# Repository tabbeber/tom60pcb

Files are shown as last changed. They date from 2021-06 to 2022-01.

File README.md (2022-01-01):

# Configuring PCB
To configure this PCB, head over to my [config repository](https://github.com/tabbeber/zmk-config). Follow the instructions there, and you should be set at modifying the keymap.

# About

This project is inspired by [isometria75](https://github.com/ebastler/isometria-75). 
Schematics and parts were used as a baseline, together with some information from the [nrfMicro-project](https://github.com/joric/nrfmicro/). 
Also thanks to Martin in the Norwegian mechanical keyboard discord for feedback and a slick logo to put on it.

What this project attempts to do is to fill a gap in the mid-tier of the custom mechanical keyboard market, where bluetooth/wireless boards are few and far between. 
Most of them are closed source or difficult to get hold of.
This is also mostly a project for me build skills within PCB design.
Feel free to come with any feedback - I have no clue what I'm doing.

This project was originally born out of an idea to create a PCB which was specifically made for gummyworm-mounting in regular tray mount cases without needing to massacre the poor case.
Eventually the PCB looked decent, and regular tray mount PCB would likely have a broader appeal than some hacky gummywork gasket.

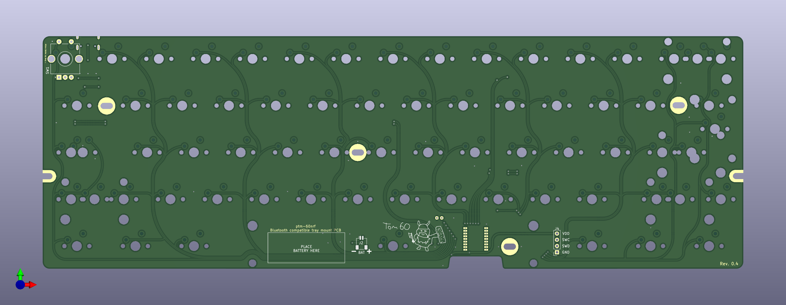
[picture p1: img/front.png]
PCB Front


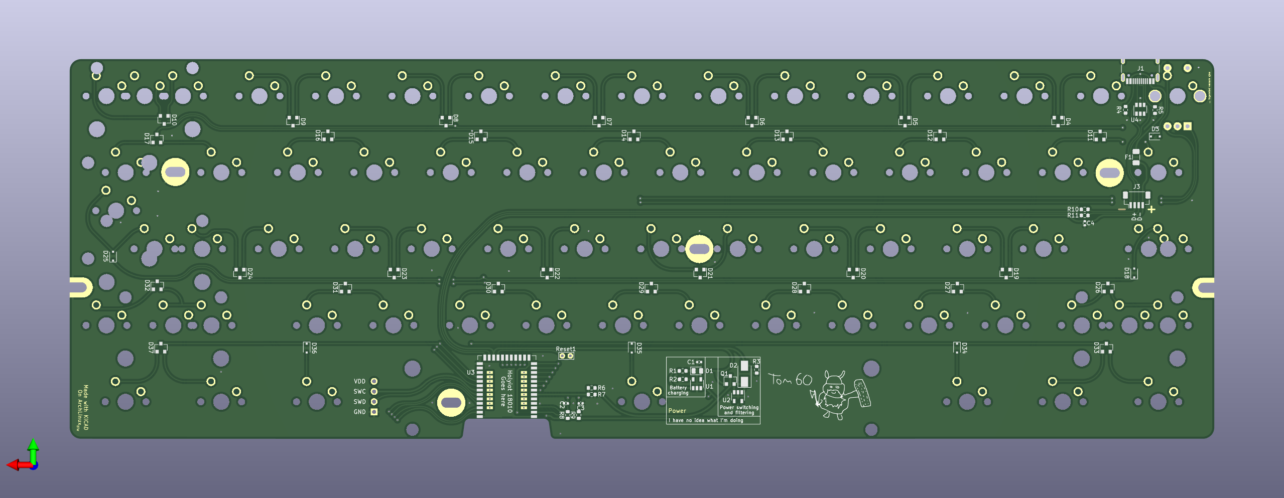
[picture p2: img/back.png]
PCB Back


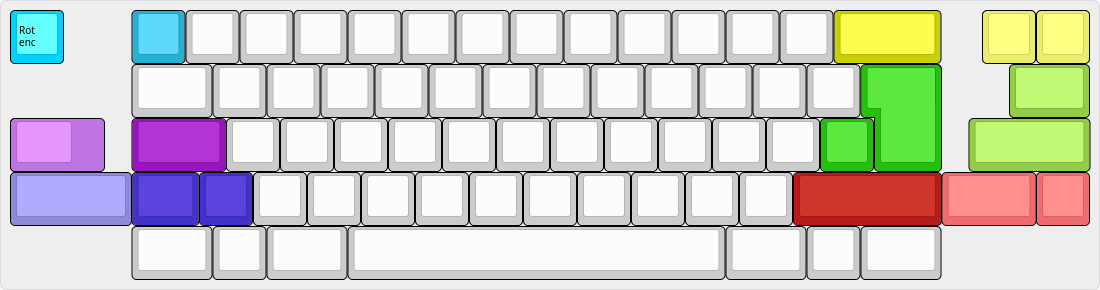
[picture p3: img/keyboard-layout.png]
Supported layouts


# Current parts

Currently this design requires a [smaller lithium battery](https://www.aliexpress.com/item/32831998939.html), which is placed between the PCB and plate of the build.
These batteries are only 3mm tall, 30mm long and 12mm wide.
This approach is not suited for plateless builds.
Ideally uses a 2-pin JST connector, but can probably also be soldered directly to the PCB.

This PCB uses the same [Holyiot 18010](https://www.aliexpress.com/item/32868002366.html) chip that the isometria75 does. This chip comes without a bootloader, and thus need to be programmed before use.

Currently the PCB uses a forced tsangan layout for the bottom row to make space for the MCU and the battery, while the rest should be fairly universal; support for split backspace, iso and ansi.

# Current progress

Currently the project requires some more work with its footprints, but it's almost ready for prototyping. No parts are currently ordered for the future prototype.

# To-do
- [x] Make a supported layout chart
- [x] Order Battery, MCU, and Programmer for the MCU
- [x] Fix PCB and final touchups
- [x] Order PCB prototype
	* PCB rev. 0.2 has arrived
	* Current revision mostly contain cosmetic changes and improved via placements - the electrical and functional configuration remain very similar to rev. 0.2
- [x] Write and configure firmware (bootloader, ZMK)
	* ZMK firmware is functional. Currently need to figure out uploading and creating a github actions repo, as per ZMK guidelines.
- [ ] Possibly make a small wiki?

# Future possibilities

* Use of different chip(format), like the nRF52840 in the E73 format, which seem abundant on aliexpress
* Modified versions for ortho, gummyworm mount, and through-hole kits.

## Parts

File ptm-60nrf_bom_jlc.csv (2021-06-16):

Comment | Designator | Footprint | LCSC Part #
1nF | C1 | C_0402_1005Metric | C1523
100nF | C2,C3 | C_0402_1005Metric | C1525
10nF | C4 | R_0402_1005Metric | C15195
RED | D1 | LED_0805_2012Metric | C84256
SS14 | D2 | D_SMA | C2480
BAV70 | D4,D5,D6,D7,D8,D9,D10,D11,D12,D13,D14,D15,D16,D17,D19,D20,D21,D22,D23,D24,D26,D27,D28,D29,D30,D31,D32,D37,D33 | SOT-23 | C68978
1n4148 | D18,D25,D34,D35,D36,D3 | D_SOD-323F | C2128
500mA | F1 | Fuse_1206_3216Metric | C70069
USB_C_Receptacle_USB2.0 | J1 | USB_C_Receptacle_HRO_TYPE-C-31-M-12 | C165948
AO3407 | Q1 | SOT-23 | C181093
1K | R1 | R_0603_1608Metric | C21190
10K | R2 | R_0603_1608Metric | C25804
100k | R3 | R_0603_1608Metric | C25803
5.1K | R4,R5 | R_0603_1608Metric | C23186
1M | R6 | R_0603_1608Metric | C22935
2M | R7 | R_0603_1608Metric | C22766
10k | R9,R8 | R_0603_1608Metric | C25804
TP4054 | U1 | SOT-23-5 | C32574
XC6220B331MR-G | U2 | SOT-23-5 | C86534
SRV05-4 | U4 | SOT-23-6 | C85364

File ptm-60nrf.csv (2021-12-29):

Id | Designator | Package | Quantity | Designation | Supplier and ref
1 | HOLE | PKRH | 1 | VAL**
2 | MX66 | MXOnly-7U-ReversedStabilizers-NoLED | 1 | MX-NoLED
3 | HOLE,HOLE,HOLE | PKRH | 3 | VAL**
4 | J2 | JST_SH_SM02B-SRSS-TB_1x02-1MP_P1.00mm_Horizontal | 1 | BAT
5 | J4 | PinSocket_1x04_P2.54mm_Vertical | 1 | SWD
6 | MX2,MX3,MX4,MX5,MX7,MX8,MX9,MX10,MX11,MX12,MX13,MX14,MX18,MX20,MX21,MX22,MX23,MX24,MX25,MX26,MX27,MX28,MX29,MX33,MX34,MX35,MX36,MX37,MX38,MX39,MX40,MX41,MX42,MX43,MX49,MX50,MX51,MX52,MX53,MX54,MX57,MX59,MX62,MX64,MX68,MX6,MX16,MX1,MX19,MX44,MX58,MX56,MX55 | MXOnly-1U-NoLED | 53 | MX-NoLED
7 | MX15 | MXOnly-2U-NoLED | 1 | MX-NoLED
8 | MX17,MX30,MX65,MX67,MX69,MX63 | MXOnly-1.5U-NoLED | 6 | MX-NoLED
9 | MX31,MX47 | MXOnly-1.25U-NoLED | 2 | MX-NoLED
10 | MX45,MX48 | MXOnly-2.25U-NoLED | 2 | MX-NoLED
11 | MX60,MX32 | MXOnly-1.75U-NoLED | 2 | MX-NoLED
12 | MX61 | MXOnly-2.75U-NoLED | 1 | MX-NoLED
13 | MX46 | MXOnly-ISO-ReversedStabilizers | 1 | MX-NoLED
14 | HOLE,HOLE | PKRHSL | 2 | VAL**
15 | SW1 | RotaryEncoder_Alps_EC11E-Switch_Vertical_H20mm | 1 | Rotary_Encoder_Switch
16 | G***,G*** | tomlogoliten | 2 | LOGO
17 | D1 | LED_0805_2012Metric | 1 | RED
18 | D18,D34,D3,D25,D35,D36 | D_SOD-323F | 6 | 1n4148
19 | Q1 | SOT-23 | 1 | AO3407
20 | R1 | R_0603_1608Metric | 1 | 1K
21 | R2 | R_0603_1608Metric | 1 | 10K
22 | R3 | R_0603_1608Metric | 1 | 100k
23 | R6 | R_0603_1608Metric | 1 | 1M
24 | U2 | SOT-23-5 | 1 | XC6220B331MR-G
25 | R7 | R_0603_1608Metric | 1 | 2M
26 | J1 | USB_C_Receptacle_HRO_TYPE-C-31-M-12 | 1 | USB_C_Receptacle_USB2.0
27 | D2 | D_SMA | 1 | SS14
28 | U3 | nRF52840_holyiot_18010 | 1 | nRF52840_holyiot_18010
29 | U4 | SOT-23-6 | 1 | SRV05-4
30 | R4,R5 | R_0603_1608Metric | 2 | 5.1K
31 | U1 | SOT-23-5 | 1 | TP4054
32 | D4,D5,D6,D7,D8,D9,D10,D13,D14,D15,D16,D17,D19,D20,D21,D22,D23,D24,D26,D27,D28,D29,D30,D32,D37,D11,D12,D31,D33 | SOT-23 | 29 | BAV70
33 | C1 | C_0402_1005Metric | 1 | 1nF
34 | J3 | JST_SH_BM04B-SRSS-TB_1x04-1MP_P1.00mm_Vertical | 1 | Conn_01x04_Male
35 | F1 | Fuse_1206_3216Metric | 1 | 500mA
36 | R10,R11 | R_0603_1608Metric | 2 | 22
37 | C4 | R_0402_1005Metric | 1 | 10nF
38 | Reset1 | TestPoint_Bridge_Pitch2.0mm_Drill0.7mm | 1 | SW_Push
39 | R8,R9 | R_0603_1608Metric | 2 | 10k
40 | C2,C3 | C_0402_1005Metric | 2 | 100nF

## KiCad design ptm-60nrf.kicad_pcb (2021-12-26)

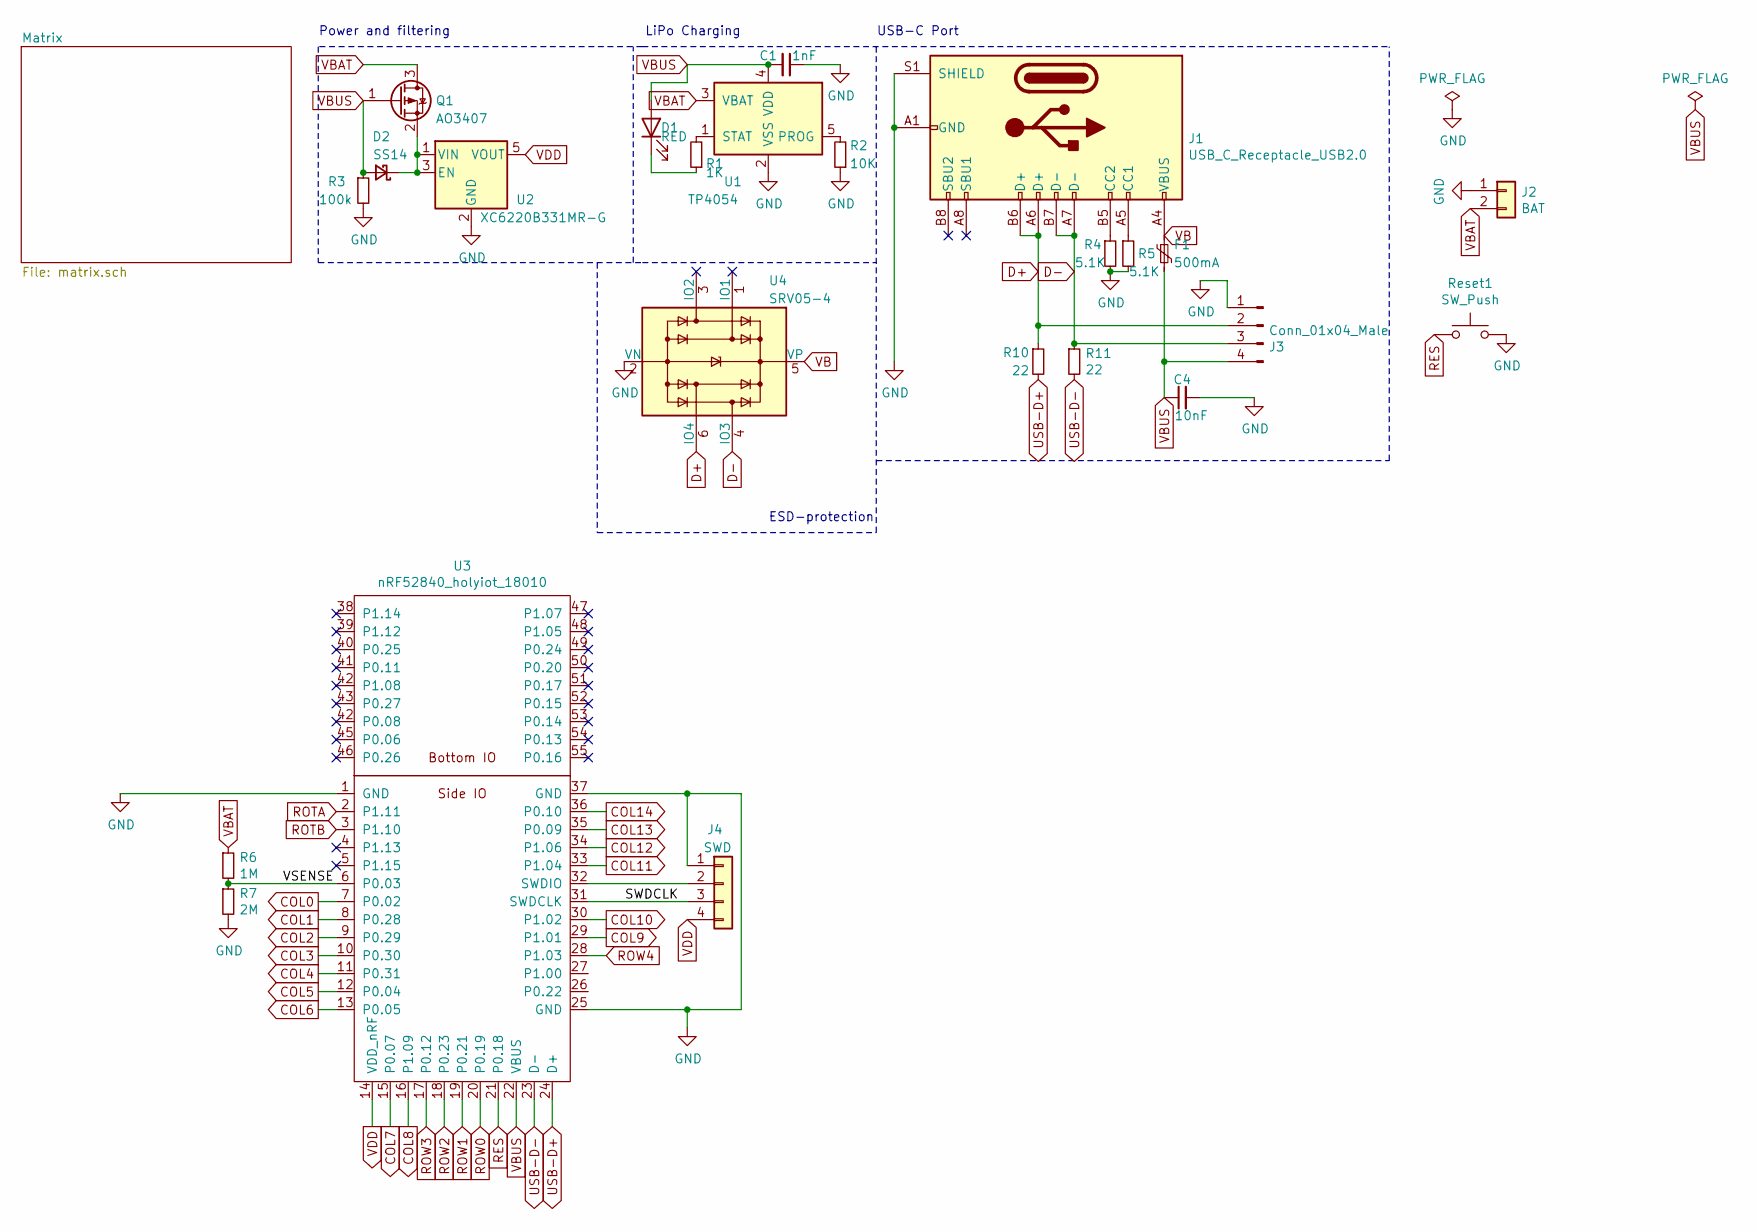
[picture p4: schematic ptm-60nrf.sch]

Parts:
C1: 1nF; C_0402_1005Metric; JLCPCB C1523
C4: 10nF; R_0402_1005Metric; JLCPCB C15195
D1: RED; LED_0805_2012Metric; JLCPCB C84256
D2: SS14; D_SMA; JLCPCB C2480
F1: 500mA; Fuse_1206_3216Metric; JLCPCB C70069
J1: USB_C_Receptacle_USB2.0; USB_C_Receptacle_HRO_TYPE-C-31-M-12; JLCPCB C165948
J2: BAT; JST_SH_SM02B-SRSS-TB_1x02-1MP_P1.00mm_Horizontal
J3: Conn_01x04_Male; JST_SH_BM04B-SRSS-TB_1x04-1MP_P1.00mm_Vertical
J4: SWD; PinSocket_1x04_P2.54mm_Vertical
Q1: AO3407; SOT-23; JLCPCB C181093
R1: 1K; R_0603_1608Metric; JLCPCB C21190
R2: 10K; R_0603_1608Metric; JLCPCB C25804
R3: 100k; R_0603_1608Metric; JLCPCB C25803
R4, R5: 5.1K; R_0603_1608Metric; JLCPCB C23186
R6: 1M; R_0603_1608Metric; JLCPCB C22935
R7: 2M; R_0603_1608Metric; JLCPCB C22766
R10, R11: 22; R_0603_1608Metric
Reset1: SW_Push; TestPoint_Bridge_Pitch2.0mm_Drill0.7mm
U1: TP4054; SOT-23-5; JLCPCB C32574
U2: XC6220B331MR-G; SOT-23-5; JLCPCB C86534
U3: nRF52840_holyiot_18010
U4: SRV05-4; SOT-23-6; JLCPCB C85364

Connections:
/SWDCLK: J4.3, U3.31 (SWDCLK)
/VSENSE: R6.2, R7.1, U3.6 (P0.03)
COL0: U3.7 (P0.02); also elsewhere on the board
COL1: U3.8 (P0.28); also elsewhere on the board
COL2: U3.9 (P0.29); also elsewhere on the board
COL3: U3.10 (P0.30); also elsewhere on the board
COL4: U3.11 (P0.31); also elsewhere on the board
COL5: U3.12 (P0.04); also elsewhere on the board
COL6: U3.13 (P0.05); also elsewhere on the board
COL7: U3.15 (P0.07); also elsewhere on the board
COL8: U3.16 (P1.09); also elsewhere on the board
COL9: U3.29 (P1.01); also elsewhere on the board
COL10: U3.30 (P1.02); also elsewhere on the board
COL11: U3.33 (P1.04); also elsewhere on the board
COL12: U3.34 (P1.06); also elsewhere on the board
COL13: U3.35 (P0.09); also elsewhere on the board
COL14: U3.36 (P0.10); also elsewhere on the board
D+: J1.A6 (D+), J1.B6 (D+), J3.2, R10.1, U4.6 (IO4)
D-: J1.A7 (D-), J1.B7 (D-), J3.3, R11.1, U4.4 (IO3)
GND: C1.1, C4.2, J1.A1 (GND), J1.A12 (GND), J1.B1 (GND), J1.B12 (GND), J1.S1 (SHIELD), J2.1, J3.1, J4.1, R2.1, R3.2, R4.2, R5.2, R7.2, Reset1.2, U1.2 (VSS), U2.2 (GND), U3.1 (GND), U3.25 (GND), U3.37 (GND), U4.2 (VN); also elsewhere on the board
unnamed: D1.1 (K), R1.1
unnamed: D2.1 (K), Q1.2 (S), U2.1 (VIN), U2.3 (EN)
unnamed: J1.A5 (CC1), R5.1
unnamed: J1.B5 (CC2), R4.1
unnamed: J4.2, U3.32 (SWDIO)
unnamed: R1.2, U1.1 (STAT)
unnamed: R2.2, U1.5 (PROG)
RES: Reset1.1, U3.21 (P0.18)
ROTA: U3.2 (P1.11); also elsewhere on the board
ROTB: U3.3 (P1.10); also elsewhere on the board
ROW0: U3.20 (P0.19); also elsewhere on the board
ROW1: U3.19 (P0.21); also elsewhere on the board
ROW2: U3.18 (P0.23); also elsewhere on the board
ROW3: U3.17 (P0.12); also elsewhere on the board
ROW4: U3.28 (P1.03); also elsewhere on the board
USB-D+: R10.2, U3.24 (D+)
USB-D-: R11.2, U3.23 (D-)
VB: F1.1, J1.A4 (VBUS), J1.A9 (VBUS), J1.B4 (VBUS), J1.B9 (VBUS), U4.5 (VP)
VBAT: J2.2, Q1.3 (D), R6.1, U1.3 (VBAT)
VBUS: C1.2, C4.1, D1.2 (A), D2.2 (A), F1.2, J3.4, Q1.1 (G), R3.1, U1.4 (VDD), U3.22 (VBUS)
VDD: J4.4, U2.5 (VOUT), U3.14 (VDD_nRF); also elsewhere on the board

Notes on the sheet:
Power and filtering
USB-C Port
LiPo Charging
ESD-protection

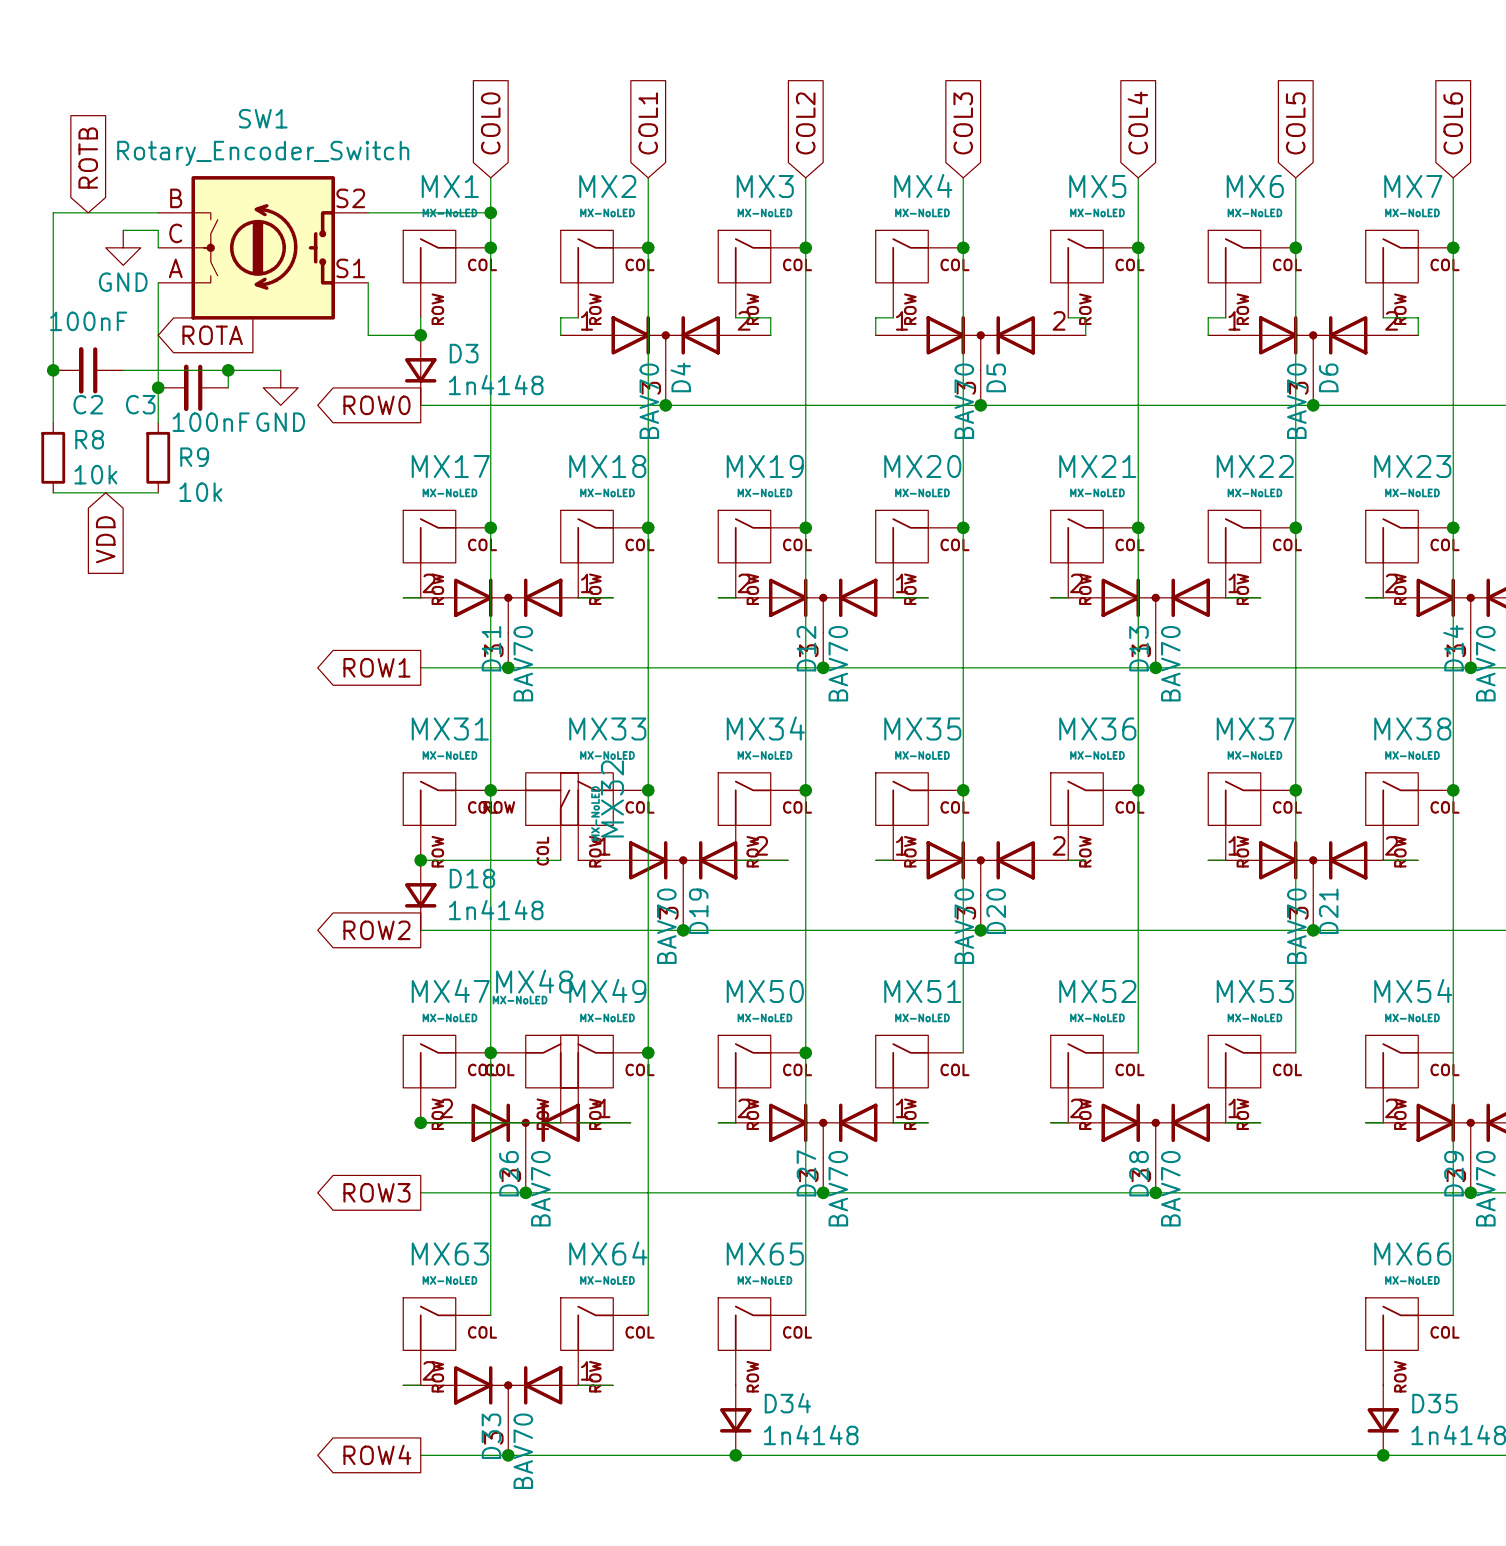
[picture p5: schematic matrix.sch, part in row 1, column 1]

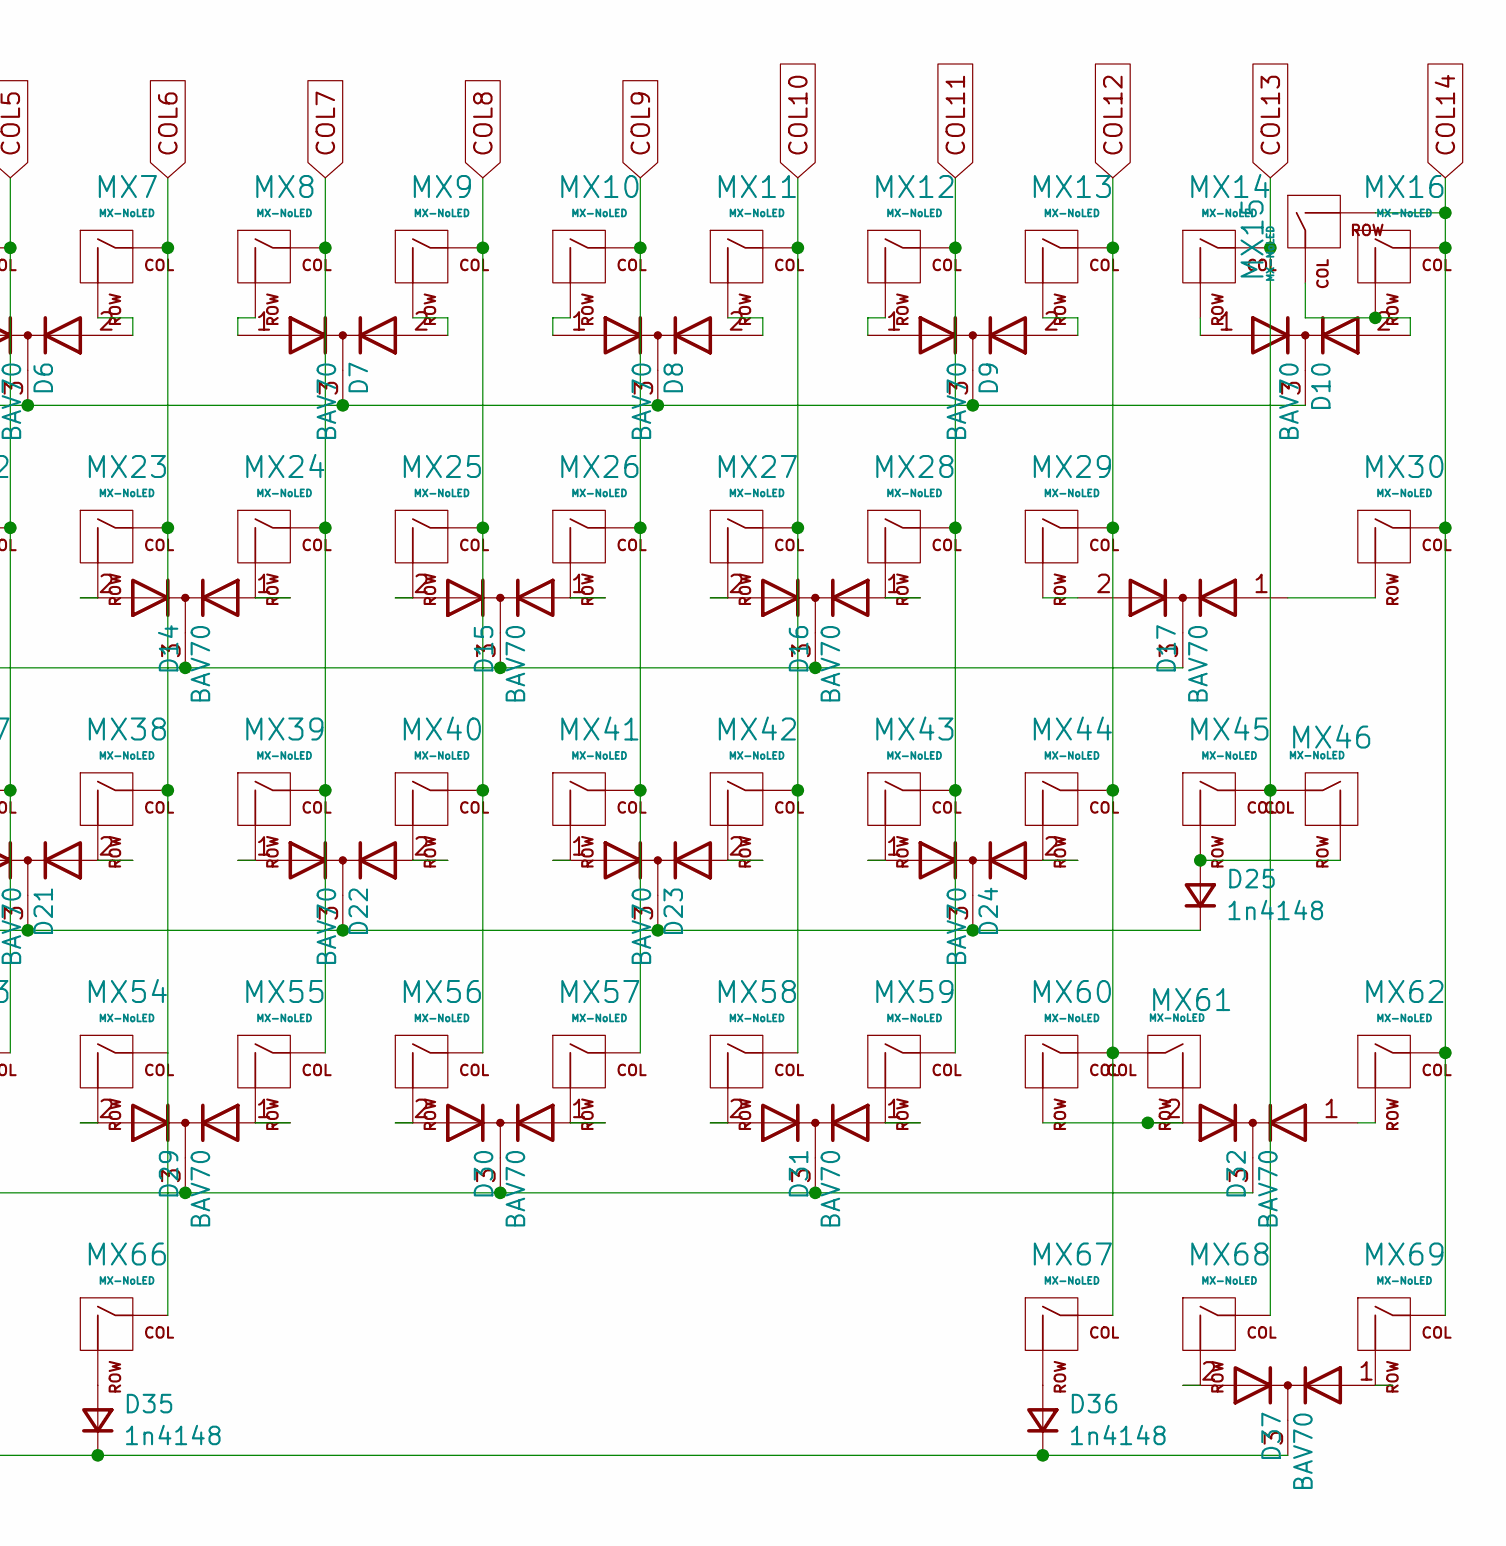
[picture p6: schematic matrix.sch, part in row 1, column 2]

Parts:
C2, C3: 100nF; C_0402_1005Metric; JLCPCB C1525
D3, D18, D25, D34, D35, D36: 1n4148; D_SOD-323F; JLCPCB C2128
D4, D5, D6, D7, D8, D9, D10, D11, D12, D13, D14, D15, D16, D17, D19, D20, D21, D22, D23, D24, D26, D27, D28, D29, D30, D31, D32, D33, D37: BAV70; SOT-23; JLCPCB C68978
MX1, MX2, MX3, MX4, MX5, MX6, MX7, MX8, MX9, MX10, MX11, MX12, MX13, MX14, MX16, MX18, MX19, MX20, MX21, MX22, MX23, MX24, MX25, MX26, MX27, MX28, MX29, MX33, MX34, MX35, MX36, MX37, MX38, MX39, MX40, MX41, MX42, MX43, MX44, MX49, MX50, MX51, MX52, MX53, MX54, MX55, MX56, MX57, MX58, MX59, MX62, MX64, MX68: MX-NoLED; MXOnly-1U-NoLED
MX15: MX-NoLED; MXOnly-2U-NoLED
MX17, MX30, MX63, MX65, MX67, MX69: MX-NoLED; MXOnly-1.5U-NoLED
MX31, MX47: MX-NoLED; MXOnly-1.25U-NoLED
MX32, MX60: MX-NoLED; MXOnly-1.75U-NoLED
MX45, MX48: MX-NoLED; MXOnly-2.25U-NoLED
MX46: MX-NoLED; MXOnly-ISO-ReversedStabilizers
MX61: MX-NoLED; MXOnly-2.75U-NoLED
MX66: MX-NoLED; MXOnly-7U-ReversedStabilizers-NoLED
R8, R9: 10k; R_0603_1608Metric; JLCPCB C25804
SW1: Rotary_Encoder_Switch; RotaryEncoder_Alps_EC11E-Switch_Vertical_H20mm

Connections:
COL0: MX1.1 (COL), MX17.1 (COL), MX31.1 (COL), MX32.2 (ROW), MX47.1 (COL), MX48.1 (COL), MX63.1 (COL), SW1.S2; also elsewhere on the board
COL1: MX2.1 (COL), MX18.1 (COL), MX33.1 (COL), MX49.1 (COL), MX64.1 (COL); also elsewhere on the board
COL2: MX3.1 (COL), MX19.1 (COL), MX34.1 (COL), MX50.1 (COL), MX65.1 (COL); also elsewhere on the board
COL3: MX4.1 (COL), MX20.1 (COL), MX35.1 (COL), MX51.1 (COL); also elsewhere on the board
COL4: MX5.1 (COL), MX21.1 (COL), MX36.1 (COL), MX52.1 (COL); also elsewhere on the board
COL5: MX6.1 (COL), MX22.1 (COL), MX37.1 (COL), MX53.1 (COL); also elsewhere on the board
COL6: MX7.1 (COL), MX23.1 (COL), MX38.1 (COL), MX54.1 (COL), MX66.1 (COL); also elsewhere on the board
COL7: MX8.1 (COL), MX24.1 (COL), MX39.1 (COL), MX55.1 (COL); also elsewhere on the board
COL8: MX9.1 (COL), MX25.1 (COL), MX40.1 (COL), MX56.1 (COL); also elsewhere on the board
COL9: MX10.1 (COL), MX26.1 (COL), MX41.1 (COL), MX57.1 (COL); also elsewhere on the board
COL10: MX11.1 (COL), MX27.1 (COL), MX42.1 (COL), MX58.1 (COL); also elsewhere on the board
COL11: MX12.1 (COL), MX28.1 (COL), MX43.1 (COL), MX59.1 (COL); also elsewhere on the board
COL12: MX13.1 (COL), MX29.1 (COL), MX44.1 (COL), MX60.1 (COL), MX61.1 (COL), MX67.1 (COL); also elsewhere on the board
COL13: MX14.1 (COL), MX45.1 (COL), MX46.1 (COL), MX68.1 (COL); also elsewhere on the board
COL14: MX15.2 (ROW), MX16.1 (COL), MX30.1 (COL), MX62.1 (COL), MX69.1 (COL); also elsewhere on the board
GND: C2.1, C3.1, SW1.C; also elsewhere on the board
unnamed: D3.2 (A), MX1.2 (ROW), SW1.S1
unnamed: D4.1 (A), MX2.2 (ROW)
unnamed: D4.2 (A), MX3.2 (ROW)
unnamed: D5.1 (A), MX4.2 (ROW)
unnamed: D5.2 (A), MX5.2 (ROW)
unnamed: D6.1 (A), MX6.2 (ROW)
unnamed: D6.2 (A), MX7.2 (ROW)
unnamed: D7.1 (A), MX8.2 (ROW)
unnamed: D7.2 (A), MX9.2 (ROW)
unnamed: D8.1 (A), MX10.2 (ROW)
unnamed: D8.2 (A), MX11.2 (ROW)
unnamed: D9.1 (A), MX12.2 (ROW)
unnamed: D9.2 (A), MX13.2 (ROW)
unnamed: D10.1 (A), MX14.2 (ROW)
unnamed: D10.2 (A), MX15.1 (COL), MX16.2 (ROW)
unnamed: D11.1 (A), MX18.2 (ROW)
unnamed: D11.2 (A), MX17.2 (ROW)
unnamed: D12.1 (A), MX20.2 (ROW)
unnamed: D12.2 (A), MX19.2 (ROW)
unnamed: D13.1 (A), MX22.2 (ROW)
unnamed: D13.2 (A), MX21.2 (ROW)
unnamed: D14.1 (A), MX24.2 (ROW)
unnamed: D14.2 (A), MX23.2 (ROW)
unnamed: D15.1 (A), MX26.2 (ROW)
unnamed: D15.2 (A), MX25.2 (ROW)
unnamed: D16.1 (A), MX28.2 (ROW)
unnamed: D16.2 (A), MX27.2 (ROW)
unnamed: D17.1 (A), MX30.2 (ROW)
unnamed: D17.2 (A), MX29.2 (ROW)
unnamed: D18.2 (A), MX31.2 (ROW), MX32.1 (COL)
unnamed: D19.1 (A), MX33.2 (ROW)
unnamed: D19.2 (A), MX34.2 (ROW)
unnamed: D20.1 (A), MX35.2 (ROW)
unnamed: D20.2 (A), MX36.2 (ROW)
unnamed: D21.1 (A), MX37.2 (ROW)
unnamed: D21.2 (A), MX38.2 (ROW)
unnamed: D22.1 (A), MX39.2 (ROW)
unnamed: D22.2 (A), MX40.2 (ROW)
unnamed: D23.1 (A), MX41.2 (ROW)
unnamed: D23.2 (A), MX42.2 (ROW)
unnamed: D24.1 (A), MX43.2 (ROW)
unnamed: D24.2 (A), MX44.2 (ROW)
unnamed: D25.2 (A), MX45.2 (ROW), MX46.2 (ROW)
unnamed: D26.1 (A), MX49.2 (ROW)
unnamed: D26.2 (A), MX47.2 (ROW), MX48.2 (ROW)
unnamed: D27.1 (A), MX51.2 (ROW)
unnamed: D27.2 (A), MX50.2 (ROW)
unnamed: D28.1 (A), MX53.2 (ROW)
unnamed: D28.2 (A), MX52.2 (ROW)
unnamed: D29.1 (A), MX55.2 (ROW)
unnamed: D29.2 (A), MX54.2 (ROW)
unnamed: D30.1 (A), MX57.2 (ROW)
unnamed: D30.2 (A), MX56.2 (ROW)
unnamed: D31.1 (A), MX59.2 (ROW)
unnamed: D31.2 (A), MX58.2 (ROW)
unnamed: D32.1 (A), MX62.2 (ROW)
unnamed: D32.2 (A), MX60.2 (ROW), MX61.2 (ROW)
unnamed: D33.1 (A), MX64.2 (ROW)
unnamed: D33.2 (A), MX63.2 (ROW)
unnamed: D34.2 (A), MX65.2 (ROW)
unnamed: D35.2 (A), MX66.2 (ROW)
unnamed: D36.2 (A), MX67.2 (ROW)
unnamed: D37.1 (A), MX69.2 (ROW)
unnamed: D37.2 (A), MX68.2 (ROW)
ROTA: C3.2, R9.1, SW1.A; also elsewhere on the board
ROTB: C2.2, R8.1, SW1.B; also elsewhere on the board
ROW0: D3.1 (K), D4.3 (K), D5.3 (K), D6.3 (K), D7.3 (K), D8.3 (K), D9.3 (K), D10.3 (K); also elsewhere on the board
ROW1: D11.3 (K), D12.3 (K), D13.3 (K), D14.3 (K), D15.3 (K), D16.3 (K), D17.3 (K); also elsewhere on the board
ROW2: D18.1 (K), D19.3 (K), D20.3 (K), D21.3 (K), D22.3 (K), D23.3 (K), D24.3 (K), D25.1 (K); also elsewhere on the board
ROW3: D26.3 (K), D27.3 (K), D28.3 (K), D29.3 (K), D30.3 (K), D31.3 (K), D32.3 (K); also elsewhere on the board
ROW4: D33.3 (K), D34.1 (K), D35.1 (K), D36.1 (K), D37.3 (K); also elsewhere on the board
VDD: R8.2, R9.2; also elsewhere on the board

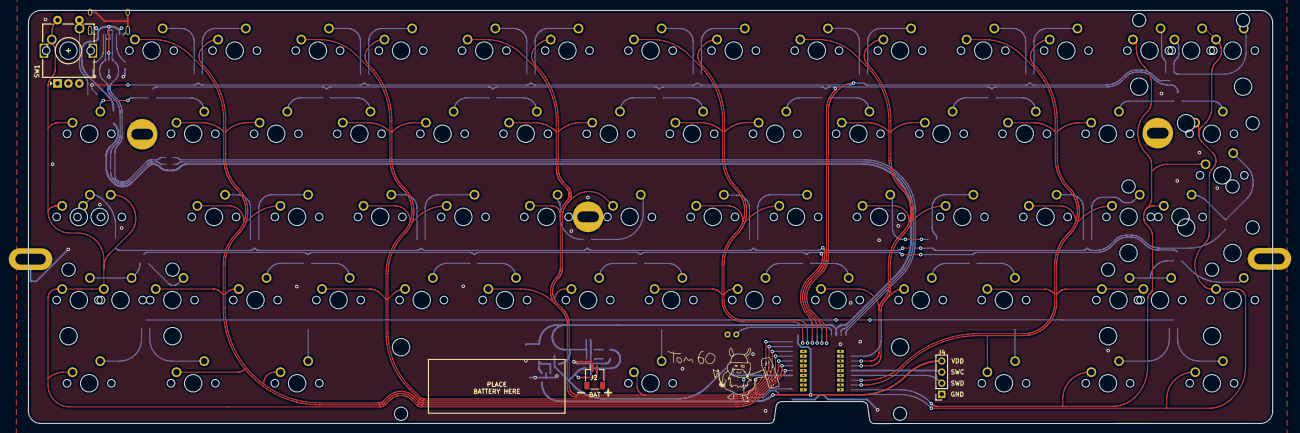
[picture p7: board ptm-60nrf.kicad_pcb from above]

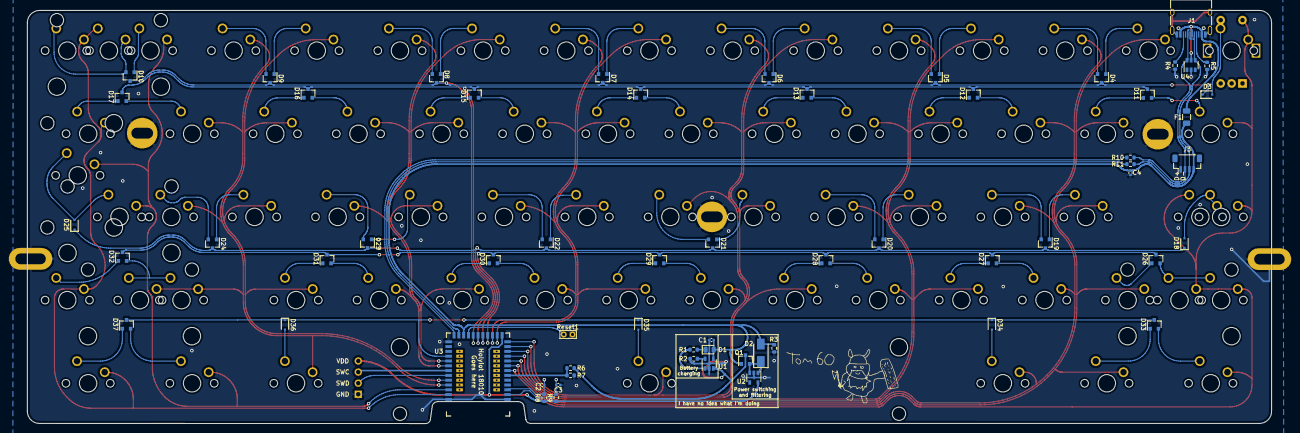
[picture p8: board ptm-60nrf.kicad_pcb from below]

Board: 2 copper layers, 285.0 x 94.6 mm, 138 parts (61 on the bottom side), 105 nets.

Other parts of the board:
HOLE: VAL**; PKRHSL
HOLE#2, HOLE#3, HOLE#4: VAL**; PKRH
HOLE#5: VAL**; PKRHSL

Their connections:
GND: HOLE.1, HOLE#2.1, HOLE#3.1, HOLE#4.1, HOLE#5.1; also elsewhere on the board

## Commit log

2021-05-31 initialise git repo for wireless 60% keyboard
    [matrix.sch, ptm-60nrf.kicad_pcb, ptm-60nrf.sch]
2021-05-31 added gerbers
    [ptm-60nrf-B_Cu.gbl, ptm-60nrf-B_Mask.gbs, ptm-60nrf-B_Paste.gbp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]
2021-05-31 added img folder for some structure
    [ptm-60nrf.kicad_pcb]
2021-05-31 fixed issues with USB tracing, grounded mounting holes and added gitignore
    [ptm-60nrf-B_Cu.gbl, ptm-60nrf-B_Mask.gbs, ptm-60nrf-B_Paste.gbp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]
2021-06-01 further changes - added copper pour, some cosmetic fixes, and changes to readme
    [ptm-60nrf-B_Cu.gbl, ptm-60nrf-B_Mask.gbs, ptm-60nrf-B_Paste.gbp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]
2021-06-01 added kle layout scheme for pcb
2021-06-01 cosmetic changes
    [ptm-60nrf-B_Cu.gbl, ptm-60nrf-B_Mask.gbs, ptm-60nrf-B_Paste.gbp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]
2021-06-01 Further improvements, moved some traces away from mounting holes
    [ptm-60nrf-B_Cu.gbl, ptm-60nrf-B_Mask.gbs, ptm-60nrf-B_Paste.gbp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]
2021-06-01 swapped reset button
    [ptm-60nrf-B_Cu.gbl, ptm-60nrf-B_Mask.gbs, ptm-60nrf-B_Paste.gbp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]
2021-06-01 fixed an upside down spacebar footprint
    [ptm-60nrf-B_Cu.gbl, ptm-60nrf-B_Mask.gbs, ptm-60nrf-B_Paste.gbp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]
2021-06-01 added some more eyecandy and fixed typos
    [ptm-60nrf-B_Cu.gbl, ptm-60nrf-B_Mask.gbs, ptm-60nrf-B_Paste.gbp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]
2021-06-02 fixed schematic flaws and caps lock (thanks Martin!)
    [matrix.sch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]
2021-06-02 added hole for antenna
    [ptm-60nrf-B_Cu.gbl, ptm-60nrf-B_Mask.gbs, ptm-60nrf-B_Paste.gbp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]
2021-06-02 increased distance between cut and antenna hole
    [ptm-60nrf-B_Cu.gbl, ptm-60nrf-B_Mask.gbs, ptm-60nrf-B_Paste.gbp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]
2021-06-02 further move traces away from cuts
    [ptm-60nrf-B_Cu.gbl, ptm-60nrf-B_Mask.gbs, ptm-60nrf-B_Paste.gbp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]
2021-06-02 minor fixes
    [matrix.sch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]
2021-06-02 restored lost artwork
    [ptm-60nrf.kicad_pcb]
2021-06-02 fixed images
    [ptm-60nrf-B_Cu.gbl, ptm-60nrf-B_Mask.gbs, ptm-60nrf-B_Paste.gbp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]
2021-06-02 squashed bugs in schematic and rewired pwr/chrg
    [ptm-60nrf-B_Cu.gbl, ptm-60nrf-B_Mask.gbs, ptm-60nrf-B_Paste.gbp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]
2021-06-02 cosmetic changes and thicker traces in power block
    [ptm-60nrf-B_Cu.gbl, ptm-60nrf-B_Mask.gbs, ptm-60nrf-B_Paste.gbp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]
2021-06-02 cosmetic changes and removal of gnd in usb bus
    [ptm-60nrf-B_Cu.gbl, ptm-60nrf-B_Mask.gbs, ptm-60nrf-B_Paste.gbp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]
2021-06-03 some cosmetic changes - might revert some
    [ptm-60nrf-B_Cu.gbl, ptm-60nrf-B_Mask.gbs, ptm-60nrf-B_Paste.gbp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]
2021-06-03 cosmetic adjustments
    [ptm-60nrf-B_Cu.gbl, ptm-60nrf-B_Mask.gbs, ptm-60nrf-B_Paste.gbp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]
2021-06-03 further cosmetic adjustments
    [ptm-60nrf-B_Cu.gbl, ptm-60nrf-B_Mask.gbs, ptm-60nrf-B_Paste.gbp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]
2021-06-03 further beautification
    [ptm-60nrf-B_Cu.gbl, ptm-60nrf-B_Mask.gbs, ptm-60nrf-B_Paste.gbp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]
2021-06-03 further improvements
    [ptm-60nrf-B_Cu.gbl, ptm-60nrf-B_Mask.gbs, ptm-60nrf-B_Paste.gbp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]
2021-06-03 created branch 0.2 for alternate mcu location. Heavy cleanup
    [ptm-60nrf-B_Cu.gbl, ptm-60nrf-B_Mask.gbs, ptm-60nrf-B_Paste.gbp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]
2021-06-04 updated branch and ordered pcb prototype
    [matrix.sch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]
2021-06-04 cosmetic improvements of a major degree - v0.3
    [ptm-60nrf-B_Cu.gbl, ptm-60nrf-B_Mask.gbs, ptm-60nrf-B_SilkS.gbo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]
2021-06-06 improved parts placements and silkscreen text (jlc compatible)
    [ptm-60nrf-B_Cu.gbl, ptm-60nrf-B_Mask.gbs, ptm-60nrf-B_SilkS.gbo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]
2021-06-07 modified to use BAV70 diodes
    [matrix.sch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]
2021-06-07 added images using BAV70 diodes
2021-06-07 rounding of traces
    [ptm-60nrf-B_Cu.gbl, ptm-60nrf-B_Mask.gbs, ptm-60nrf-B_SilkS.gbo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]
2021-06-08 further changes
    [ptm-60nrf-B_Cu.gbl, ptm-60nrf-B_Mask.gbs, ptm-60nrf-B_SilkS.gbo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]
2021-06-08 improved symmetry
    [ptm-60nrf-B_Cu.gbl, ptm-60nrf-B_Mask.gbs, ptm-60nrf-B_SilkS.gbo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]
2021-06-08 discovered a way to copy and paste traces reliably
    [ptm-60nrf-B_Cu.gbl, ptm-60nrf-B_Mask.gbs, ptm-60nrf-B_SilkS.gbo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]
2021-06-08 further corner smoothing
    [ptm-60nrf-B_Cu.gbl, ptm-60nrf-B_Mask.gbs, ptm-60nrf-B_SilkS.gbo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]
2021-06-08 prototype pcb en route, readme reflecting that
2021-06-09 added footprint for rotary encoder on esc - renamed v0.4
    [matrix.sch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]
2021-06-12 added support for daughterboard (jst footprint)
    [ptm-60nrf-B_Cu.gbl, ptm-60nrf-B_Mask.gbs, ptm-60nrf-B_SilkS.gbo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]
2021-06-16 swapped switch to pads (savings), added resistor to data
    [ptm-60nrf-B_Cu.gbl, ptm-60nrf-B_Mask.gbs, ptm-60nrf-B_SilkS.gbo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]
2021-12-20 swapped polarity on battery connector… Other minor fixes
    [ptm-60nrf-B_Cu.gbl, ptm-60nrf-B_Mask.gbs, ptm-60nrf-B_SilkS.gbo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]
2021-12-26 changing encoder traces
    [ptm-60nrf.kicad_pcb]
2021-12-29 moved MCU in order to properly support Tofu and Mekanisk with addition standoffs
    [ptm-60nrf-B_Cu.gbl, ptm-60nrf-B_Mask.gbs, ptm-60nrf-Edge_Cuts.gm1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]
2022-01-01 moved traces, fixed curves
    [ptm-60nrf-B_Cu.gbl, ptm-60nrf-B_Mask.gbs, ptm-60nrf-Edge_Cuts.gm1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]
2022-01-01 fixed a trace
